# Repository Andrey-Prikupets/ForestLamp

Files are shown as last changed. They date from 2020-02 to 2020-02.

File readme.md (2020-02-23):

# Forest Lamp

Electronic and firmware for that lamp is based on [AlexGyver LED Lamp](https://github.com/AlexGyver/GyverLamp).
The lamp itself is 3D printed as 75% more resized version of that ["resized" model](https://www.thingiverse.com/thing:2657068), which is the remix from original [Forest Lamp](https://www.thingiverse.com/thing:1491062). 
ESP8266 board (I used WeMos D1 mini) runs modified AlexGyver's firmware, where I made some configuration changes, tweaks for stability and flickering removal.
Also I added additional features which are controlled via RemoteXY Android app.

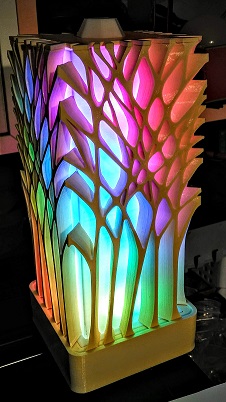
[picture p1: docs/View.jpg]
View


## 3D model changes

I made few additional models and did not use light core. 

* LED core for 8 WS2812 LED stripes with 5 LEDs each (it is low density stripe, stripe with higher number of LEDs is preferable);
* Top cap for the LED core to make it attachable with bolt and nut to the lamp walls and roof;
* Bottom cap to cover gaps between lamp walls and base;
* Crystal-like nut to attach lamp case to the top cap and LED core.

The idea is to disassemble the lamp with only 1 nut.

Models are uploaded to **Thingiverse** [https://www.thingiverse.com/thing:4147654](https://www.thingiverse.com/thing:4147654) :gem:.

## Additional features exposed via RemoteXY app

* Simplified color selection, brightness control and grayscale;
* Alternative on/off switch;
* Special control for focusing lamp beam (a la "radar");
* Russian language interface;

## Parts

* WeMos D1 min;
* 40 WS2812 LEDs on the stripe, cut to 8 pieces by 5 LEDs each.
* 10k resistor pull-up from RST pin to 3.3V;
* 0.1uF ceramic capacitor between 3.3V pin to GND pin (in fact, to the closest pin of RESET button, which is connected to GND);

The last 2 items should decrease chance of freezing ESP8266 on power-up.

## Libraries

* [Modifed version](libraries/RemoteXYap) of [RemoteXY](http://remotexy.com) library where I removed code that creates connection and configures WiFi module (because AlegGyver firmware already does it in a better way).
The library should be placed into library folder as usual.
* All libraries required by AlexGyver's lamp (FastLED etc.).

Note: I also considered using Virtuino, but amazing RGB control and joystick control in RemoteXY forced me to choose RemoteXY.

## RemoteXY UI

RemoteXY UI should be available by [link](http://remotexy.com/en/editor/b432a2957787b45cd5d483b4a82bf226/). 
It works even in free version of RemoteXY Android app, because contains less than 5 controls.
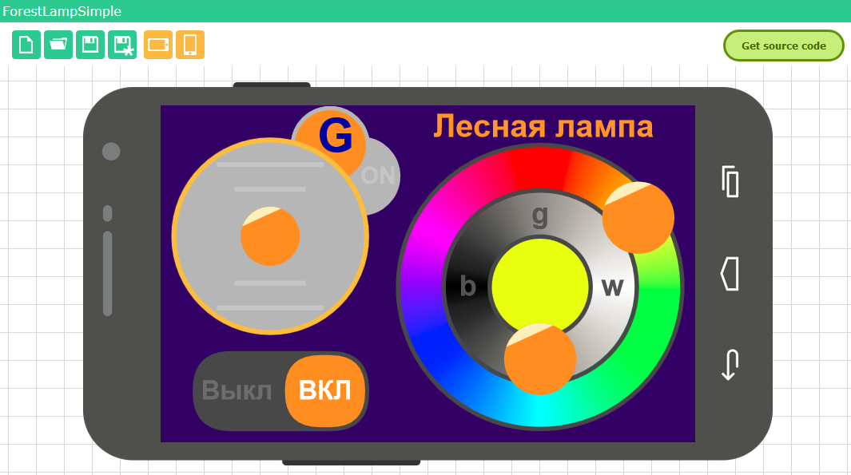
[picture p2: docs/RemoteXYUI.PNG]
UI in designer


## Models
Please see them in [models folder](models). 

## Building photos
Please see them in [docs folder](docs). 

## Internet enabled firmware

Primary firmware is in [firmware/ForestLamp](firmware/ForestLamp) folder.

## Alternative firmware without Internet control

If internet control is not needed, there is an alternative firmware based on Arduino 328p. Effects are changed by pot (variable resistor).
Please see it in [firmware/ForestLampNI](firmware/ForestLampNI) folder.
Video: [https://youtu.be/wpEpOciEXpc](https://youtu.be/wpEpOciEXpc).

## TODO
* Add videos
* Re-enable WDT;

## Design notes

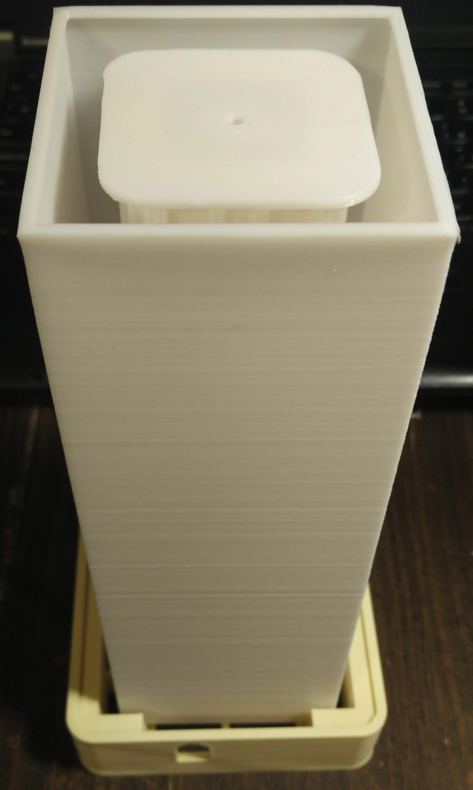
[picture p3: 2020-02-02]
docs/light_core_with_cap2.jpg

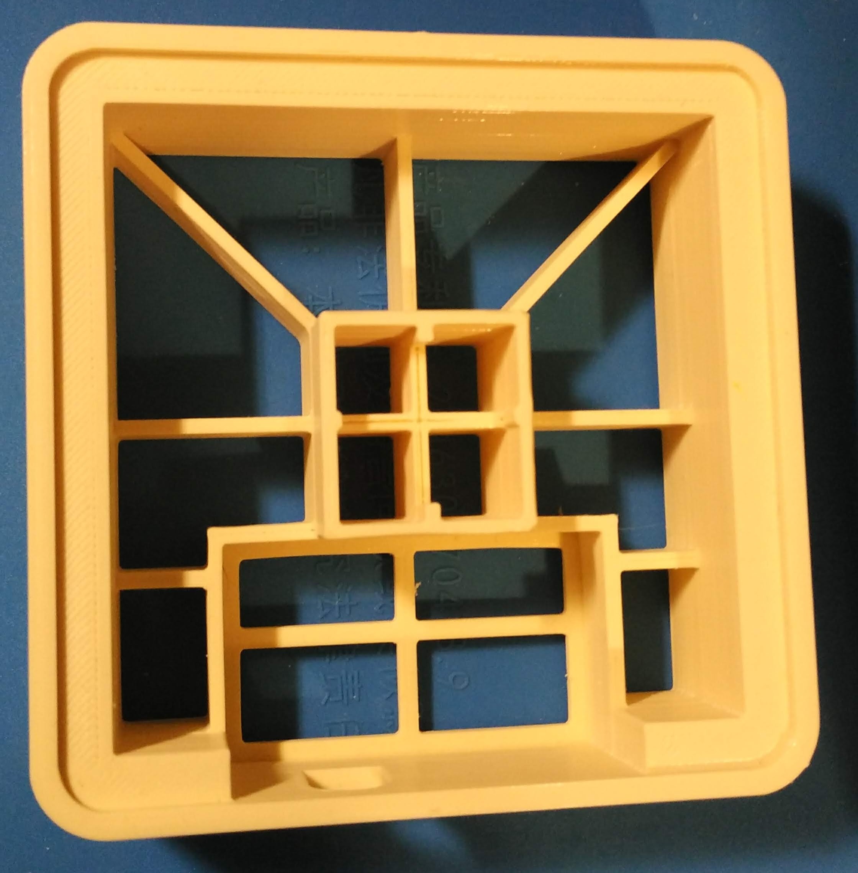
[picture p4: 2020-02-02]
docs/base.jpg

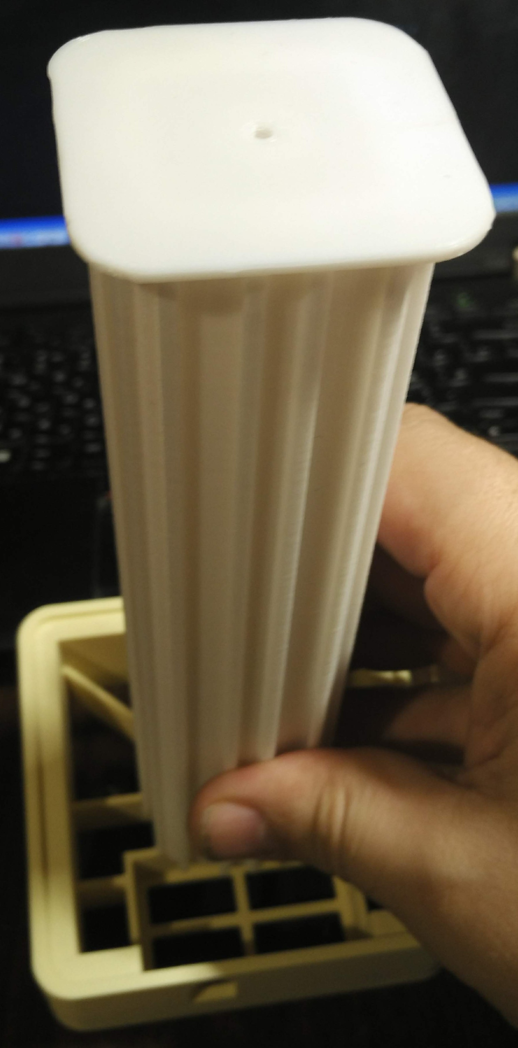
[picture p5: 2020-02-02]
docs/light_core_with_cap_and_base.jpg

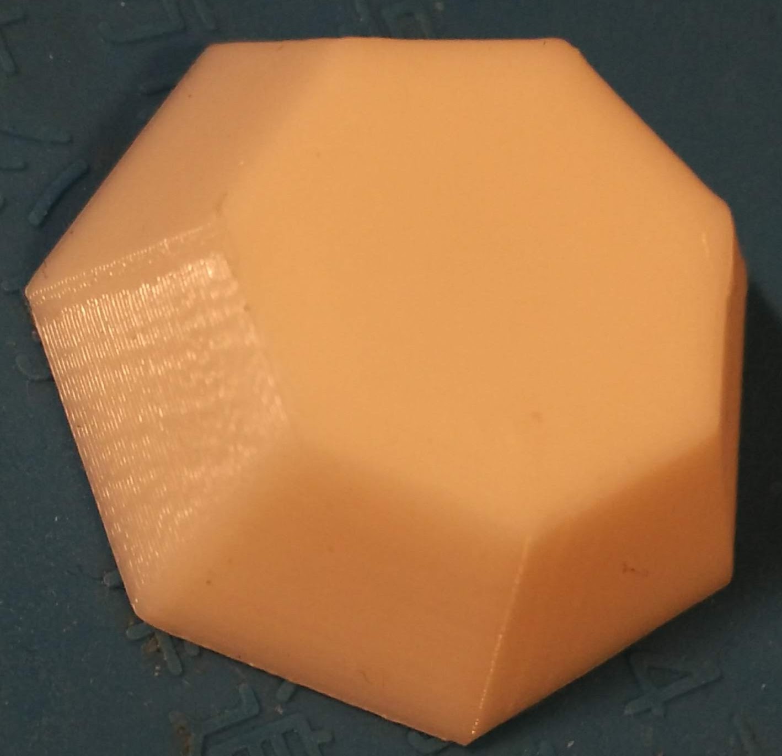
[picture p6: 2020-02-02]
docs/Nut_with_insert_top_view.jpg

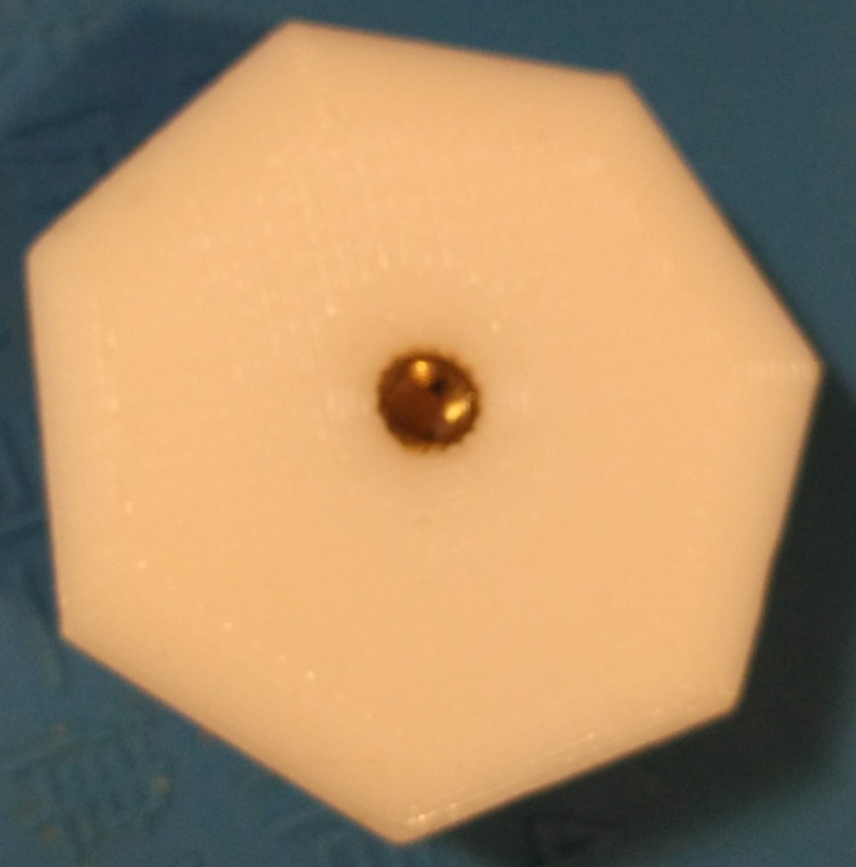
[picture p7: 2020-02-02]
docs/Nut_with_insert_bottom_view.jpg

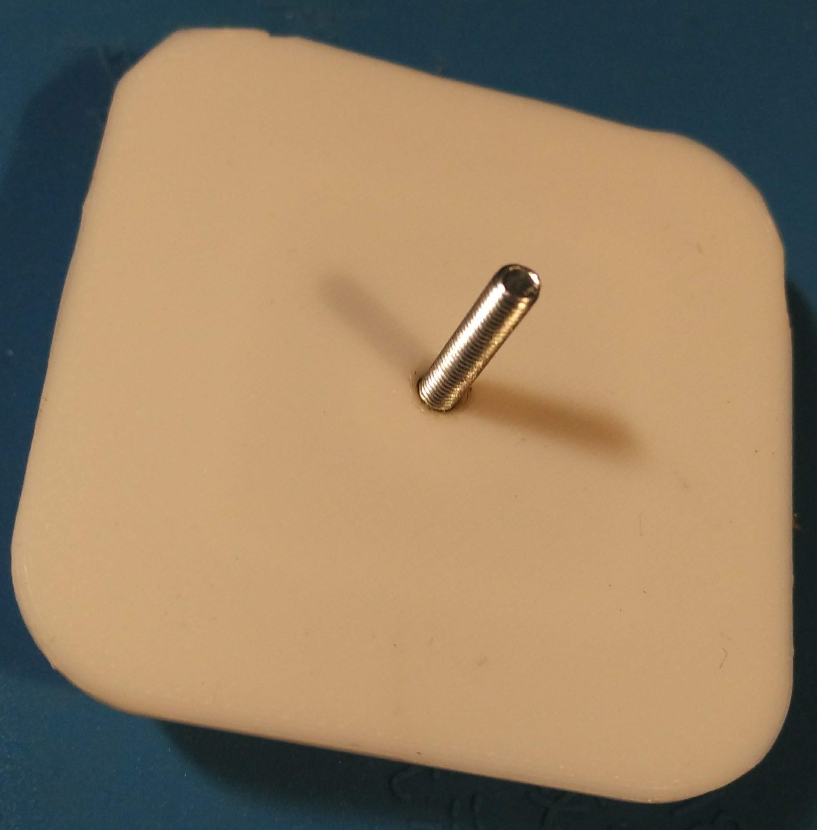
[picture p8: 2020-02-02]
docs/top_cap_top_view.jpg

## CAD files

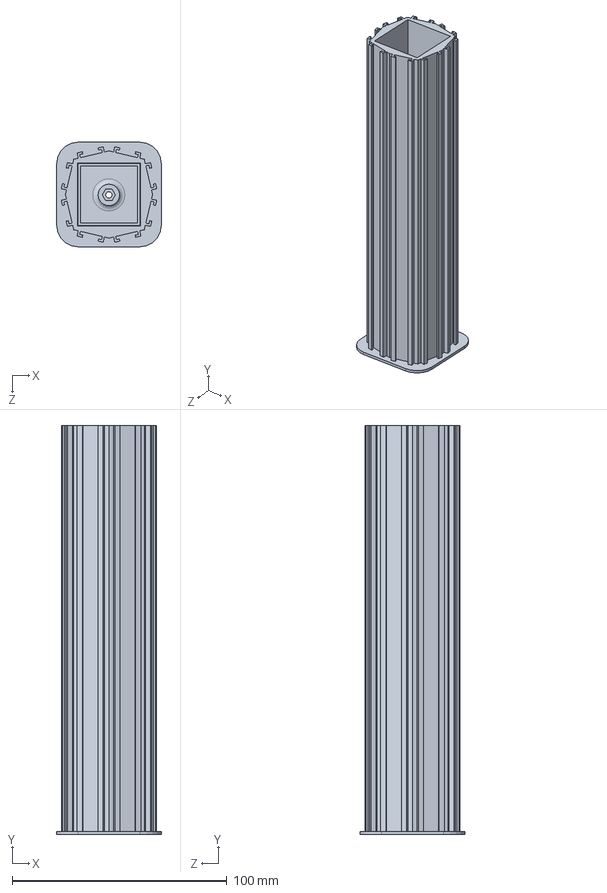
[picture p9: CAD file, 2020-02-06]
models/Light_Pole_and_Top.SLDPRT
48.7 x 190.5 x 48.8 mm

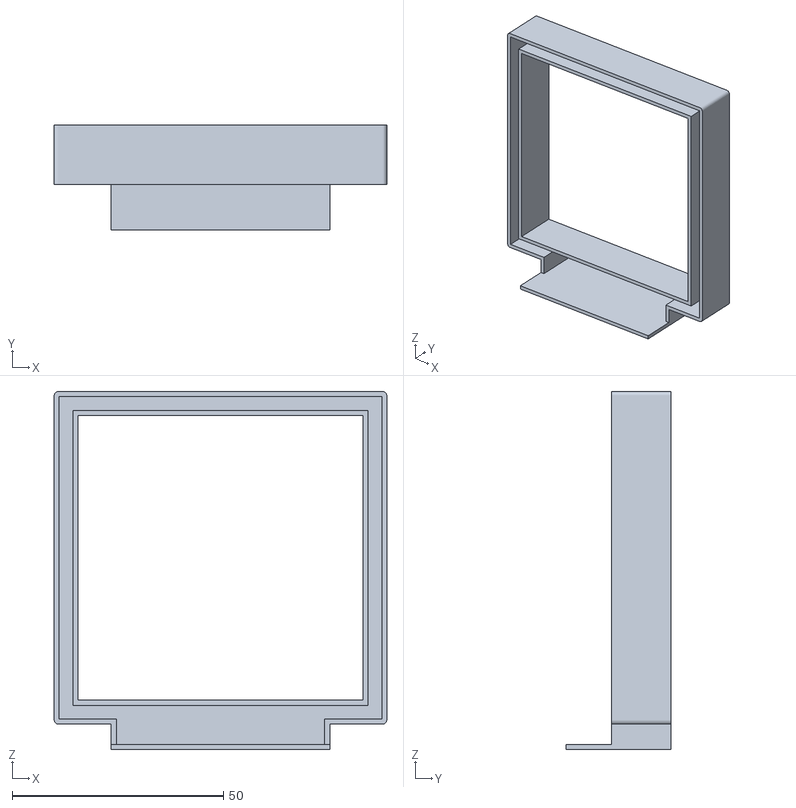
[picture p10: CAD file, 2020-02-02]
models/Lamp_bottom_insert1.STL
78.8 x 24.8 x 84.8

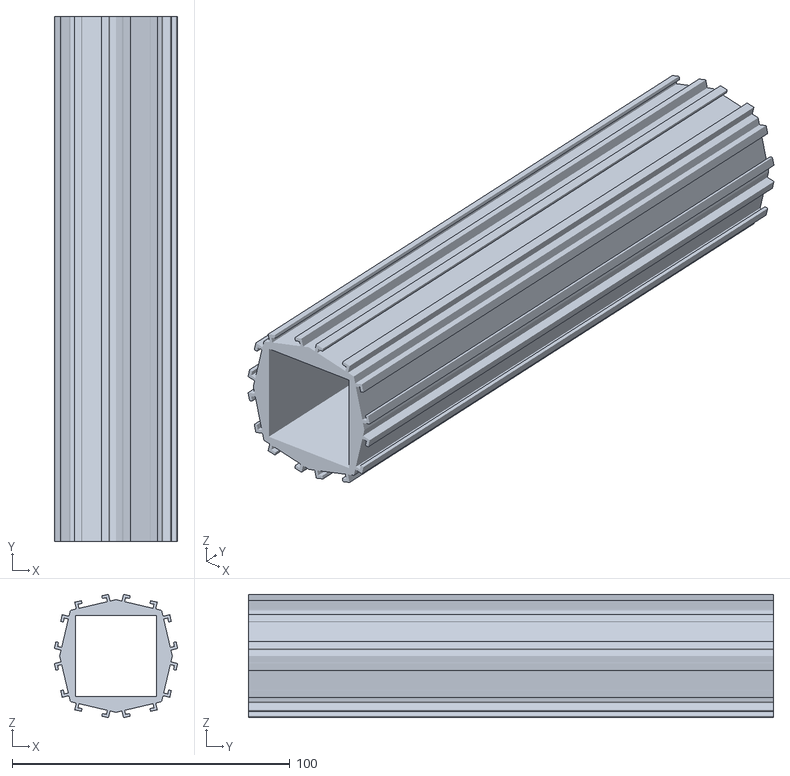
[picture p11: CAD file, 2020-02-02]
models/Light_Pole.STL
44.4 x 189.0 x 44.4

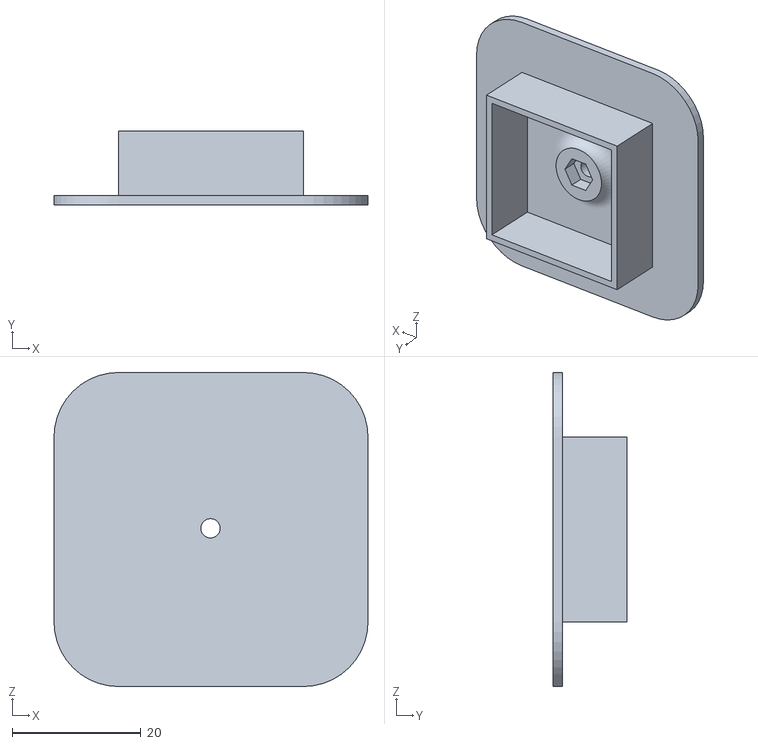
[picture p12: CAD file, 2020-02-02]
models/Light_Pole_Top.STL
48.8 x 11.5 x 48.8

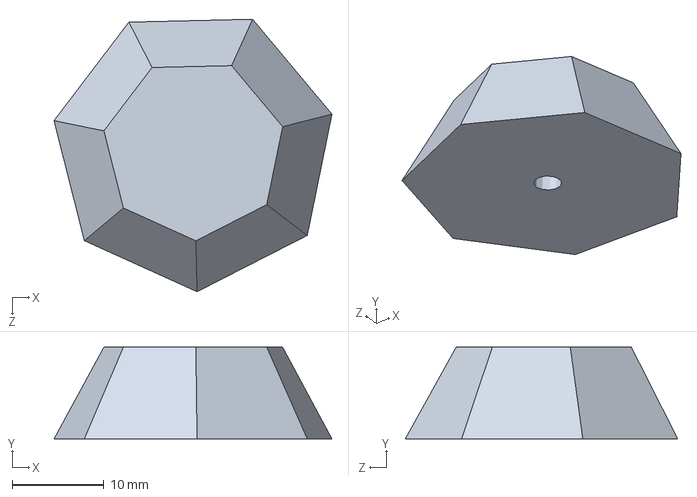
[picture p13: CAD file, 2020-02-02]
models/Lamp Nut.SLDPRT
30.3 x 10.0 x 29.7 mm

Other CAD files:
models/Lamp_bottom_insert.SLDPRT
models/Lamp Nut.STL

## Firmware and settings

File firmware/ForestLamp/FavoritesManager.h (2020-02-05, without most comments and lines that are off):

#pragma once
#include <EEPROM.h>
#include "EepromManager.h"
#include "Constants.h"
#define DEFAULT_FAVORITES_INTERVAL           (300U)         // значение по умолчанию для интервала переключения избранных эффектов в секундах
#define DEFAULT_FAVORITES_DISPERSION         (0U)           // значение по умолчанию для разброса интервала переключения избранных эффектов в секундах
class FavoritesManager
{
  public:
    static uint8_t FavoritesRunning;                        // флаг "работает режим автоматической смены избранных эффектов"
    static uint16_t Interval;                               // статический интервал (время между сменами эффектов)
    static uint16_t Dispersion;                             // дополнительный динамический (случайный) интервал (время между сменами эффектов)
    static uint8_t UseSavedFavoritesRunning;                // флаг, определяющий, нужно ли использовать сохранённое значение FavoritesRunning при перезапуске; еслин нет, "избранное" будет выключено при старте
    static uint8_t FavoriteModes[MODE_AMOUNT];              // массив, каждый элемент которого соответствует флагу "эффект №... добавлен в избранные"
    static void SetStatus(char* statusText)                 // помещает в statusText состояние режима работы избранных эффектов
    {
      char buff[6];
      strcpy_P(statusText, PSTR("FAV "));
      itoa(FavoritesRunning, buff, 10);
      strcat(statusText, buff);
      strcat_P(statusText, PSTR(" "));
      buff[0] = '\0';
      itoa(Interval, buff, 10);
      strcat(statusText, buff);
      strcat_P(statusText, PSTR(" "));
      buff[0] = '\0';
      itoa(Dispersion, buff, 10);
      strcat(statusText, buff);
      strcat_P(statusText, PSTR(" "));
      buff[0] = '\0';
      itoa(UseSavedFavoritesRunning, buff, 10);
      strcat(statusText, buff);
      strcat_P(statusText, PSTR(" "));
      buff[0] = '\0';
      for (uint8_t i = 0; i < MODE_AMOUNT; i++)
      {
        itoa(FavoriteModes[i], buff, 10);
        strcat(statusText, buff);
        if (i < MODE_AMOUNT - 1) strcat_P(statusText, PSTR(" "));
        buff[0] = '\0';
      }
      statusText += '\0';
    }
    static void ConfigureFavorites(const char* statusText)  // принимает statusText, парсит его и инициализирует свойства класса значениями из statusText'а
    {
      FavoritesRunning = getFavoritesRunning(statusText);
      if (FavoritesRunning == 0)
      {
        nextModeAt = 0;
      }
      Interval = getInterval(statusText);
      Dispersion = getDispersion(statusText);
      UseSavedFavoritesRunning = getUseSavedFavoritesRunning(statusText);
      for (uint8_t i = 0; i < MODE_AMOUNT; i++)
      {
        FavoriteModes[i] = getModeOnOff(statusText, i);
      }
    }
    static bool HandleFavorites(                            // функция, обрабатывающая циклическое переключение избранных эффектов; возвращает true, если эффект был переключен
      bool* ONflag,
      int8_t* currentMode,
      bool* loadingFlag
      #ifdef USE_NTP
      , bool* dawnFlag
      #endif
    )
    {
      if (FavoritesRunning == 0 ||
          !*ONflag                                          // лампа не переключается на следующий эффект при выключенной матрице
          #ifdef USE_NTP
          || *dawnFlag                                      // лампа не переключается на следующий эффект при включенном будильнике
          #endif
      )
      {
        return false;
      }
      if (nextModeAt == 0)                                  // лампа не переключается на следующий эффект сразу после включения режима избранных эффектов
      {
        nextModeAt = getNextTime();
        return false;
      }
      if (millis() >= nextModeAt)
      {
        *currentMode = getNextFavoriteMode(currentMode);
        *loadingFlag = true;
        nextModeAt = getNextTime();
        #ifdef GENERAL_DEBUG
        LOG.printf_P(PSTR("Переключение на следующий избранный режим: %d\n\n"), (*currentMode));
        #endif
        return true;
      }
      return false;
    }
    static void ReadFavoritesFromEeprom()
    {
      Interval = EepromManager::ReadUint16(EEPROM_FAVORITES_START_ADDRESS + 1);
      Dispersion = EepromManager::ReadUint16(EEPROM_FAVORITES_START_ADDRESS + 3);
      UseSavedFavoritesRunning = EEPROM.read(EEPROM_FAVORITES_START_ADDRESS + 5);
      FavoritesRunning = UseSavedFavoritesRunning > 0 ? EEPROM.read(EEPROM_FAVORITES_START_ADDRESS) : FavoritesRunning;
      for (uint8_t i = 0; i < MODE_AMOUNT; i++)
      {
        FavoriteModes[i] = EEPROM.read(EEPROM_FAVORITES_START_ADDRESS + i + 6);
        FavoriteModes[i] = FavoriteModes[i] > 0 ? 1 : 0;
      }
    }
    static void SaveFavoritesToEeprom()
    {
      LOG.printf_P(PSTR("SaveFavoritesToEeprom, start=%d\n"), EEPROM_FAVORITES_START_ADDRESS);
      EEPROM.put(EEPROM_FAVORITES_START_ADDRESS, FavoritesRunning);
      EepromManager::WriteUint16(EEPROM_FAVORITES_START_ADDRESS + 1, Interval);
      EepromManager::WriteUint16(EEPROM_FAVORITES_START_ADDRESS + 3, Dispersion);
      EEPROM.put(EEPROM_FAVORITES_START_ADDRESS + 5, UseSavedFavoritesRunning);
      for (uint8_t i = 0; i < MODE_AMOUNT; i++)
      {
        int address = EEPROM_FAVORITES_START_ADDRESS + i + 6;
        EEPROM.put(address, (uint8_t)(FavoriteModes[i] > 0 ? 1 : 0));
      }
      EEPROM.commit();
    }
    static void TurnFavoritesOff()
    {
      FavoritesRunning = 0;
      nextModeAt = 0;
    }
  private:
    static uint32_t nextModeAt;                             // ближайшее время переключения на следующий избранный эффект (millis())
    static bool isStatusTextCorrect(const char* statusText) // валидирует statusText (проверяет, правильное ли количество компонентов он содержит)
    {
      char buff[MAX_UDP_BUFFER_SIZE];
      strcpy(buff, statusText);
      uint8_t lexCount = 0;
      char* p = strtok(buff, " ");
      while (p != NULL)                                   // пока есть лексемы...
      {
        lexCount++;
        p = strtok(NULL, " ");
      }
      return lexCount == getStatusTextNormalComponentsCount();
    }
    static uint8_t getStatusTextNormalComponentsCount()     // возвращает правильное ли коичество компонентов для statusText в зависимости от определённого формата команды и количества эффектов
    {
      return
        1 +          // "FAV"
        1 +          // вкл/выкл
        1 +          // интервал
        1 +          // разброс
        1 +          // использовать ли хранимый вкл/выкл
        MODE_AMOUNT; // 0/1 для каждого эффекта
    }
    static uint8_t getFavoritesRunning(const char* statusText)        // возвращает признак вкл/выкл режима избранных эффектов из statusText
    {
      char lexem[2];
      memset(lexem, 0, 2);
      strcpy(lexem, getLexNo(statusText, 1));
      return lexem != NULL
        ? !strcmp(lexem, "1")
        : 0;
    }
    static uint16_t getInterval(const char* statusText)     // возвращает интервал (постоянную составляющую) переключения избранных эффектов из statusText
    {
      char lexem[6];
      memset(lexem, 0, 6);
      strcpy(lexem, getLexNo(statusText, 2));
      return lexem != NULL
        ? atoi((const char*)lexem)
        : DEFAULT_FAVORITES_INTERVAL;
    }
    static uint16_t getDispersion(const char* statusText)   // возвращает разброс (случайную составляющую) интервала переключения избранных эффектов из statusText
    {
      char lexem[6];
      memset(lexem, 0, 6);
      strcpy(lexem, getLexNo(statusText, 3));
      return lexem != NULL
        ? atoi((const char*)lexem)
        : DEFAULT_FAVORITES_DISPERSION;
    }
    static uint8_t getUseSavedFavoritesRunning(const char* statusText)// возвращает признак вкл/выкл режима избранных эффектов из statusText
    {
      char lexem[2];
      memset(lexem, 0, 2);
      strcpy(lexem, getLexNo(statusText, 4));
      return lexem != NULL
        ? !strcmp(lexem, "1")
        : 0;
    }
    static bool getModeOnOff(const char* statusText, uint8_t modeId)  // возвращает признак включения указанного эффекта в избранные эффекты
    {
      char lexem[2];
      memset(lexem, 0, 2);
      strcpy(lexem, getLexNo(statusText, modeId + 5));
      return lexem != NULL
        ? !strcmp(lexem, "1")
        : false;
    }
    static char* getLexNo(const char* statusText, uint8_t pos)        // служебная функция, разбивает команду statusText на лексемы ("слова", разделённые пробелами) и возвращает указанную по счёту лексему
    {
      if (!isStatusTextCorrect(statusText))
      {
        return NULL;
      }
      const uint8_t buffSize = MAX_UDP_BUFFER_SIZE;
      char buff[buffSize];
      memset(buff, 0, buffSize);
      strcpy(buff, statusText);
      uint8_t lexPos = 0;
      char* p = strtok(buff, " ");
      while (p != NULL)                                   // пока есть лексемы...
      {
        if (lexPos == pos)
        {
          return p;
        }
        p = strtok(NULL, " ");
        lexPos++;
      }
      return NULL;
    }
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

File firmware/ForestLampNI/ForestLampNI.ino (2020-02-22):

#include <FastLED.h>

FASTLED_USING_NAMESPACE


#if defined(FASTLED_VERSION) && (FASTLED_VERSION < 3001000)
#warning "Requires FastLED 3.1 or later; check github for latest code."
#endif

#define POT_PIN     A1
#define OFF_PIN     3

#define DATA_PIN    2
#define LED_TYPE    WS2812

#define WIDTH                 (8U)  // ширина матрицы
#define HEIGHT                (11U) // высота матрицы

#define COLOR_ORDER           (GRB) // порядок цветов на ленте. Если цвет отображается некорректно - меняйте. Начать можно с RGB

#define MATRIX_TYPE           (0U)  // тип матрицы: 0 - зигзаг, 1 - параллельная
#define CONNECTION_ANGLE      (0U)  // угол подключения: 0 - левый нижний, 1 - левый верхний, 2 - правый верхний, 3 - правый нижний
#define STRIP_DIRECTION       (1U)  // направление ленты из угла: 0 - вправо, 1 - вверх, 2 - влево, 3 - вниз
                                    // при неправильной настройке матрицы вы получите предупреждение "Wrong matrix parameters! Set to default"
                                    // шпаргалка по настройке матрицы здесь! https://alexgyver.ru/matrix_guide/
#define NUM_LEDS              (uint16_t)(WIDTH * HEIGHT)
CRGB leds[NUM_LEDS];

#define BRIGHTNESS         255 // 0-255
#define FRAMES_PER_SECOND  120

#define NUM_READINGS          (10)

#define SEGMENTS              (1U)                          // диодов в одном "пикселе" (для создания матрицы из кусков ленты)

uint8_t gCurrentPatternNumber = 0; // Index number of which pattern is current
uint8_t gHue = 0; // rotating "base color" used by many of the patterns

bool loadingFlag = true;
unsigned char matrixValue[8][16];

// Scale in range 1..100;
// Delay in ms;
#define FIRE_SCALE        10 // yellow fire;
#define FIRE_DELAY        10

#define RAINBOW_VER_SCALE 25 // 10
#define RAINBOW_VER_DELAY 100

#define RAINBOW_HOR_SCALE 10
#define RAINBOW_HOR_DELAY 100

#define RAINBOW_DIAG_SCALE 15
#define RAINBOW_DIAG_DELAY 80

#define MATRIX_SCALE      50
#define MATRIX_DELAY      100

static const uint8_t maxDim = max(WIDTH, HEIGHT);

// START; Effects from FastLed's DemoReel;

void rainbow() 
{
  // FastLED's built-in rainbow generator
  fill_rainbow( leds, NUM_LEDS, gHue, 7);
}

void rainbowWithGlitter() 
{
  // built-in FastLED rainbow, plus some random sparkly glitter
  rainbow();
  addGlitter(80);
}

void addGlitter( fract8 chanceOfGlitter) 
{
  if( random8() < chanceOfGlitter) {
    leds[ random16(NUM_LEDS) ] += CRGB::White;
  }
}

void confetti() 
{
  // random colored speckles that blink in and fade smoothly
  fadeToBlackBy( leds, NUM_LEDS, 10);
  int pos = random16(NUM_LEDS);
  leds[pos] += CHSV( gHue + random8(64), 200, 255);
}

void sinelon()
{
  // a colored dot sweeping back and forth, with fading trails
  fadeToBlackBy( leds, NUM_LEDS, 20);
  int pos = beatsin16( 13, 0, NUM_LEDS-1 );
  leds[pos] += CHSV( gHue, 255, 192);
}

void bpm()
{
  // colored stripes pulsing at a defined Beats-Per-Minute (BPM)
  uint8_t BeatsPerMinute = 62;
  CRGBPalette16 palette = PartyColors_p;
  uint8_t beat = beatsin8( BeatsPerMinute, 64, 255);
  for( int i = 0; i < NUM_LEDS; i++) { //9948
    leds[i] = ColorFromPalette(palette, gHue+(i*2), beat-gHue+(i*10));
  }
}

void juggle() {
  // eight colored dots, weaving in and out of sync with each other
  fadeToBlackBy( leds, NUM_LEDS, 20);
  byte dothue = 0;
  for( int i = 0; i < 8; i++) {
    leds[beatsin16( i+7, 0, NUM_LEDS-1 )] |= CHSV(dothue, 200, 255);
    dothue += 32;
  }
}

// END; Effects from FastLed's DemoReel;

// START; Effects from AlexGyver's WiFi Lamp;

// служебные функции

// залить все
void fillAll(CRGB color)
{
  for (int32_t i = 0; i < NUM_LEDS; i++)
  {
    leds[i] = color;
  }
}

// функция отрисовки точки по координатам X Y
void drawPixelXY(int16_t x, int16_t y, CRGB color)
{
  if (x < 0 || x > (int16_t)(WIDTH - 1) || y < 0 || y > (int16_t)(HEIGHT - 1)) return;
  uint32_t thisPixel = getPixelNumber((uint8_t)x, (uint8_t)y) * SEGMENTS;
  for (uint8_t i = 0; i < SEGMENTS; i++)
  {
    leds[thisPixel + i] = color;
  }
}

// функция получения цвета пикселя по его номеру
uint32_t getPixColor(uint32_t thisSegm)
{
  uint32_t thisPixel = thisSegm * SEGMENTS;
  if (thisPixel > NUM_LEDS - 1) return 0;
  return (((uint32_t)leds[thisPixel].r << 16) | ((uint32_t)leds[thisPixel].g << 8 ) | (uint32_t)leds[thisPixel].b);
}

// функция получения цвета пикселя в матрице по его координатам
uint32_t getPixColorXY(uint8_t x, uint8_t y)
{
  return getPixColor(getPixelNumber(x, y));
}

// ************* НАСТРОЙКА МАТРИЦЫ *****
#if (CONNECTION_ANGLE == 0 && STRIP_DIRECTION == 0)
#define _WIDTH WIDTH
#define THIS_X x
#define THIS_Y y

#elif (CONNECTION_ANGLE == 0 && STRIP_DIRECTION == 1)
#define _WIDTH HEIGHT
#define THIS_X y
#define THIS_Y x

#elif (CONNECTION_ANGLE == 1 && STRIP_DIRECTION == 0)
#define _WIDTH WIDTH
#define THIS_X x
#define THIS_Y (HEIGHT - y - 1)

#elif (CONNECTION_ANGLE == 1 && STRIP_DIRECTION == 3)
#define _WIDTH HEIGHT
#define THIS_X (HEIGHT - y - 1)
#define THIS_Y x

#elif (CONNECTION_ANGLE == 2 && STRIP_DIRECTION == 2)
#define _WIDTH WIDTH
#define THIS_X (WIDTH - x - 1)
#define THIS_Y (HEIGHT - y - 1)

#elif (CONNECTION_ANGLE == 2 && STRIP_DIRECTION == 3)
#define _WIDTH HEIGHT
#define THIS_X (HEIGHT - y - 1)
#define THIS_Y (WIDTH - x - 1)

#elif (CONNECTION_ANGLE == 3 && STRIP_DIRECTION == 2)
#define _WIDTH WIDTH
#define THIS_X (WIDTH - x - 1)
#define THIS_Y y

#elif (CONNECTION_ANGLE == 3 && STRIP_DIRECTION == 1)
#define _WIDTH HEIGHT
#define THIS_X y
#define THIS_Y (WIDTH - x - 1)

#else
#define _WIDTH WIDTH
#define THIS_X x
#define THIS_Y y
#pragma message "Wrong matrix parameters! Set to default"

#endif

// получить номер пикселя в ленте по координатам
uint16_t getPixelNumber(uint8_t x, uint8_t y)
{
  if ((THIS_Y % 2 == 0) || MATRIX_TYPE)                     // если чётная строка
  {
    return (THIS_Y * _WIDTH + THIS_X);
  }
  else                                                      // если нечётная строка
  {
    return (THIS_Y * _WIDTH + _WIDTH - THIS_X - 1);
  }
}

uint8_t line[WIDTH];
uint8_t pcnt = 0U;
#define SPARKLES              (1U)                          // вылетающие угольки вкл выкл

//these values are substracetd from the generated values to give a shape to the animation
static const uint8_t valueMask[8][16] PROGMEM =
{
  {32 , 0  , 0  , 0  , 0  , 0  , 0  , 32 , 32 , 0  , 0  , 0  , 0  , 0  , 0  , 32 },
  {64 , 0  , 0  , 0  , 0  , 0  , 0  , 64 , 64 , 0  , 0  , 0  , 0  , 0  , 0  , 64 },
  {96 , 32 , 0  , 0  , 0  , 0  , 32 , 96 , 96 , 32 , 0  , 0  , 0  , 0  , 32 , 96 },
  {128, 64 , 32 , 0  , 0  , 32 , 64 , 128, 128, 64 , 32 , 0  , 0  , 32 , 64 , 128},
  {160, 96 , 64 , 32 , 32 , 64 , 96 , 160, 160, 96 , 64 , 32 , 32 , 64 , 96 , 160},
  {192, 128, 96 , 64 , 64 , 96 , 128, 192, 192, 128, 96 , 64 , 64 , 96 , 128, 192},
  {255, 160, 128, 96 , 96 , 128, 160, 255, 255, 160, 128, 96 , 96 , 128, 160, 255},
  {255, 192, 160, 128, 128, 160, 192, 255, 255, 192, 160, 128, 128, 160, 192, 255}
};

//these are the hues for the fire,
//should be between 0 (red) to about 25 (yellow)
static const uint8_t hueMask[8][16] PROGMEM =
{
  {1 , 11, 19, 25, 25, 22, 11, 1 , 1 , 11, 19, 25, 25, 22, 11, 1 },
  {1 , 8 , 13, 19, 25, 19, 8 , 1 , 1 , 8 , 13, 19, 25, 19, 8 , 1 },
  {1 , 8 , 13, 16, 19, 16, 8 , 1 , 1 , 8 , 13, 16, 19, 16, 8 , 1 },
  {1 , 5 , 11, 13, 13, 13, 5 , 1 , 1 , 5 , 11, 13, 13, 13, 5 , 1 },
  {1 , 5 , 11, 11, 11, 11, 5 , 1 , 1 , 5 , 11, 11, 11, 11, 5 , 1 },
  {0 , 1 , 5 , 8 , 8 , 5 , 1 , 0 , 0 , 1 , 5 , 8 , 8 , 5 , 1 , 0 },
  {0 , 0 , 1 , 5 , 5 , 1 , 0 , 0 , 0 , 0 , 1 , 5 , 5 , 1 , 0 , 0 },
  {0 , 0 , 0 , 1 , 1 , 0 , 0 , 0 , 0 , 0 , 0 , 1 , 1 , 0 , 0 , 0 }
};

void fireRoutine()
{
  if (loadingFlag)
  {
    loadingFlag = false;
    FastLED.clear();
    generateLine();
    memset(matrixValue, 0, sizeof(matrixValue));
  }
  EVERY_N_MILLISECONDS( FIRE_DELAY ) {
    if (pcnt >= 100)
    {
      shiftUp();
      generateLine();
      pcnt = 0;
    }
    drawFrame(pcnt, true);
    pcnt += 30;
  }
}

// Randomly generate the next line (matrix row)
void generateLine()
{
  for (uint8_t x = 0U; x < WIDTH; x++)
  {
    line[x] = random(64, 255);
  }
}

void shiftUp()
{
  for (uint8_t y = HEIGHT - 1U; y > 0U; y--)
  {
    for (uint8_t x = 0U; x < WIDTH; x++)
    {
      uint8_t newX = x;
      if (x > 15U) newX = x % 16U;
      if (y > 7U) continue;
      matrixValue[y][newX] = matrixValue[y - 1U][newX];
    }
  }

  for (uint8_t x = 0U; x < WIDTH; x++)
  {
    uint8_t newX = x;
    if (x > 15U) newX = x % 16U;
    matrixValue[0U][newX] = line[newX];
  }
}

// draw a frame, interpolating between 2 "key frames"
// @param pcnt percentage of interpolation

void drawFrame(uint8_t pcnt, bool isColored)
{
  int32_t nextv;

  //each row interpolates with the one before it
  for (uint8_t y = HEIGHT - 1U; y > 0U; y--)
  {
    for (uint8_t x = 0U; x < WIDTH; x++)
    {
      uint8_t newX = x;
      if (x > 15U) newX = x % 16U;
      if (y < 8U)
      {
        nextv =
          (((100.0 - pcnt) * matrixValue[y][newX]
            + pcnt * matrixValue[y - 1][newX]) / 100.0)
          - pgm_read_byte(&valueMask[y][newX]);

        CRGB color = CHSV(
          isColored ? FIRE_SCALE * 2.5 + pgm_read_byte(&hueMask[y][newX]) : 0U,     // H
          isColored ? 255U : 0U,                                                               // S
          (uint8_t)max(0, nextv)                                                               // V
        );

        leds[getPixelNumber(x, y)] = color;
      }
      else if (y == 8U && SPARKLES)
      {
        if (random(0, 20) == 0 && getPixColorXY(x, y - 1U) != 0U) drawPixelXY(x, y, getPixColorXY(x, y - 1U));
        else drawPixelXY(x, y, 0U);
      }
      else if (SPARKLES)
      {
        // старая версия для яркости
        if (getPixColorXY(x, y - 1U) > 0U)
          drawPixelXY(x, y, getPixColorXY(x, y - 1U));
        else drawPixelXY(x, y, 0U);
      }
    }
  }

  //first row interpolates with the "next" line
  for (uint8_t x = 0U; x < WIDTH; x++)
  {
    uint8_t newX = x;
    if (x > 15U) newX = x % 16U;
    CRGB color = CHSV(
      isColored ? FIRE_SCALE * 2.5 + pgm_read_byte(&(hueMask[0][newX])): 0U,        // H
      isColored ? 255U : 0U,                                                                   // S
      (uint8_t)(((100.0 - pcnt) * matrixValue[0][newX] + pcnt * line[newX]) / 100.0)           // V
    );
    //leds[getPixelNumber(newX, 0)] = color;                                         // на форуме пишут что это ошибка - вместо newX должно быть x, иначе
    leds[getPixelNumber(x, 0)] = color;                                              // на матрицах шире 16 столбцов нижний правый угол неработает
  }
}

// ------------- радуга вертикальная ----------------
// uint8_t hue;

#define hue gHue

void rainbowVerticalRoutine()
{
  EVERY_N_MILLISECONDS( RAINBOW_VER_DELAY ) {
    hue += 4;
    for (uint8_t j = 0; j < HEIGHT; j++)
    {
      CHSV thisColor = CHSV((uint8_t)(hue + j * RAINBOW_VER_SCALE), 255, 255);
      for (uint8_t i = 0U; i < WIDTH; i++)
      {
        drawPixelXY(i, j, thisColor);
      }
    }
  }
}

// ------------- радуга горизонтальная ----------------
void rainbowHorizontalRoutine()
{
  EVERY_N_MILLISECONDS( RAINBOW_HOR_DELAY ) {
    hue += 4;
    for (uint8_t i = 0U; i < WIDTH; i++)
    {
      CHSV thisColor = CHSV((uint8_t)(hue + i * RAINBOW_HOR_SCALE), 255, 255);
      for (uint8_t j = 0U; j < HEIGHT; j++)
      {
        drawPixelXY(i, j, thisColor);
      }
    }
  }
}

// ------------- радуга диагональная -------------
void rainbowDiagonalRoutine()
{
  if (loadingFlag)
  {
    loadingFlag = false;
    FastLED.clear();
  }

  EVERY_N_MILLISECONDS( RAINBOW_DIAG_DELAY ) {
    hue += 8;
    for (uint8_t i = 0U; i < WIDTH; i++)
    {
      for (uint8_t j = 0U; j < HEIGHT; j++)
      {
        float twirlFactor = 3.0F * (RAINBOW_DIAG_SCALE / 100.0F);      // на сколько оборотов будет закручена матрица, [0..3]
        uint8_t hue1 = (uint8_t)(hue + ((float)WIDTH / (float)HEIGHT * i + j * twirlFactor) * (float)(255 / maxDim));
        CRGB thisColor = CHSV(hue1, 255, 255);
        drawPixelXY(i, j, thisColor);
      }
    }
  }
}

// ------------- матрица ---------------
void matrixRoutine()
{
  if (loadingFlag)
  {
    loadingFlag = false;
    FastLED.clear();
  }
  EVERY_N_MILLISECONDS( MATRIX_DELAY ) {
    for (uint8_t x = 0U; x < WIDTH; x++)
    {
      // заполняем случайно верхнюю строку
      uint32_t thisColor = getPixColorXY(x, HEIGHT - 1U);
      if (thisColor == 0U)
        drawPixelXY(x, HEIGHT - 1U, 0x00FF00 * (random(0, 100 - MATRIX_SCALE) == 0U));
      else if (thisColor < 0x002000)
        drawPixelXY(x, HEIGHT - 1U, 0U);
      else
        drawPixelXY(x, HEIGHT - 1U, thisColor - 0x002000);
    }
  
    // сдвигаем всё вниз
    for (uint8_t x = 0U; x < WIDTH; x++)
    {
      for (uint8_t y = 0U; y < HEIGHT - 1U; y++)
      {
        drawPixelXY(x, y, getPixColorXY(x, y + 1U));
      }
    }
  }
}

// END; Effects from AlexGyver's WiFi Lamp;

int readings[NUM_READINGS];     // the readings from the analog input

void setup() {
  Serial.begin(115200);
  // tell FastLED about the LED strip configuration
  FastLED.addLeds<LED_TYPE,DATA_PIN,COLOR_ORDER>(leds, NUM_LEDS).setCorrection(TypicalLEDStrip);
  // set master brightness control
  FastLED.setBrightness(BRIGHTNESS);

  pinMode(POT_PIN, INPUT); // set pin to input;
  digitalWrite(POT_PIN, LOW); // disable pull-ups;
     
  pinMode(OFF_PIN, INPUT); // set pin to input;
  digitalWrite(OFF_PIN, HIGH); // enable pull-ups;
  
  for (int i = 0; i < NUM_READINGS; i++) {
    readings[i] = 0;
  }

  memset(matrixValue, 0, sizeof(matrixValue));
  randomSeed(micros());
  loadingFlag = true;
}

static int rawValue = 0;

int getValueAvg() {
  static int readIndex = 0;              // the index of the current reading
  static int total = 0;                  // the running total
  
  // subtract the last reading:
  total = total - readings[readIndex];
  // read from the sensor:
  rawValue = analogRead(POT_PIN);
  readings[readIndex] = rawValue;
  // add the reading to the total:
  total = total + readings[readIndex];
  // advance to the next position in the array:
  readIndex = readIndex + 1;

  // if we're at the end of the array...
  if (readIndex >= NUM_READINGS) {
    // ...wrap around to the beginning:
    readIndex = 0;
  }

  // calculate the average:
  return total / NUM_READINGS;
}

#define ADC_MAX 1023

int getValue() {
  int value = ADC_MAX-getValueAvg();
  static int value1 = -1;
  if (value != value1) {
//    Serial.print("value="); Serial.print(value,DEC);
//    Serial.print(", rawValue="); Serial.println(rawValue,DEC);
    value1 = value;
  } else {
//    Serial.print("rawValue="); Serial.println(rawValue,DEC);  
  }
  return value;  
}

// List of patterns to cycle through.  Each is defined as a separate function below.
typedef void (*SimplePatternList[])();
//   rainbow,            
//   juggle,              
//   rainbowWithGlitter, 
//   bpm,
SimplePatternList gPatterns = { 
   confetti,            
   sinelon,             
   fireRoutine,
   rainbowVerticalRoutine,
   rainbowHorizontalRoutine,
   rainbowDiagonalRoutine,
   matrixRoutine
  };              

#define ARRAY_SIZE(A) (sizeof(A) / sizeof((A)[0]))

#define SAFE_LIMIT 100 // dirty hack to handle out of range values;
#define POT_MIN 0
#define POT_MAX ADC_MAX
#define POT_MIN_SAFE (POT_MIN-SAFE_LIMIT)
#define POT_MAX_SAFE (POT_MAX+SAFE_LIMIT)
#define POT_WHITE_MIN 0
#define POT_WHITE_MIN_SAFE POT_MIN_SAFE
#define POT_WHITE_MAX 40
#define POT_COLORS_MIN POT_WHITE_MAX+1
#define POT_COLORS_MAX (POT_MAX/4)
#define EFFECTS_MIN (POT_COLORS_MAX+1)
#define EFFECTS_MAX (POT_MAX-40)
#define DEMO_MIN (EFFECTS_MAX+1)
#define DEMO_MAX POT_MAX
#define DEMO_MAX_SAFE POT_MAX_SAFE
#define EFFECTS_RANGE (EFFECTS_MAX-EFFECTS_MIN+1)
#define EFFECTS_NUM ARRAY_SIZE(gPatterns)
#define EFFECTS_STEP (EFFECTS_RANGE/EFFECTS_NUM)

#define HIST_STEP ((EFFECTS_STEP+7)/8)

void nextPattern()
{
  // add one to the current pattern number, and wrap around at the end
  gCurrentPatternNumber = (gCurrentPatternNumber + 1) % ARRAY_SIZE( gPatterns);
  Serial.print(F("Pattern ")); Serial.println(gCurrentPatternNumber, DEC);
}

void setAllLeds(CHSV color) {
  CRGB col = (CRGB) color;
  for( int i = 0; i < NUM_LEDS; i++) {
    leds[i] = col;
  }  
}

bool inRange1(int value, int minValue, int maxValue) {
  return value >= minValue && value <= maxValue;
}

bool inRange(int value, int minValue, int maxValue) {
  static int prevValue = -1;
  bool prevValueInRange = inRange1(prevValue, minValue, maxValue);
  bool fit;
//  Serial.print(F("prevValueInRange=")); Serial.print(prevValueInRange, DEC);
  if (prevValueInRange) {
//    Serial.print(F(", step=")); Serial.print(HIST_STEP, DEC);
    fit = inRange1(value, minValue-HIST_STEP, maxValue+HIST_STEP);
  } else {
    fit = inRange1(value, minValue+HIST_STEP, maxValue-HIST_STEP);    
  }
  if (fit) {
    prevValue = (maxValue+minValue)/2;
  }
//  Serial.print(F(" [")); Serial.print(minValue, DEC);
//  Serial.print(F(",")); Serial.print(maxValue, DEC);
//  Serial.print(F("], value=")); Serial.print(value, DEC);
//  Serial.print(F(", fit=")); Serial.println(fit, DEC);
  return fit;
}

bool isSwitched(int pos) {
  static int pos1 = -1;
  if (pos != pos1) {
    Serial.print(F("Triggered to ")); Serial.println(pos, DEC);
    pos1 = pos;
    return true;
  }
  return false;
}

void loop()
{
  // insert a delay to keep the framerate modest
  FastLED.delay(1000/FRAMES_PER_SECOND); 

  if (digitalRead(OFF_PIN)) {
    FastLED.clear();
    FastLED.show();  
    return;
  }

  int value = getValue();
  if (inRange(value, POT_WHITE_MIN_SAFE, POT_WHITE_MAX)) {
    isSwitched(POT_WHITE_MIN);
    setAllLeds(CHSV(0, 0, 255));
  } else
  if (inRange(value, POT_COLORS_MIN, POT_COLORS_MAX)) {
    isSwitched(POT_COLORS_MIN);
    int hue = constrain(map(value,POT_COLORS_MIN,POT_COLORS_MAX,0,255), 0, 255);
    setAllLeds(CHSV(hue, 255, 255));
  } else
  if (inRange(value, EFFECTS_MIN, EFFECTS_MAX)) {
    int effect = map(value,EFFECTS_MIN,EFFECTS_MAX,0,EFFECTS_NUM);
    #define ARTIFICIAL_EFFECTS_HASH_BASE 10000
    if (isSwitched(ARTIFICIAL_EFFECTS_HASH_BASE+effect)) {
      loadingFlag = true;  
      gHue = 0;
    }
    EVERY_N_MILLISECONDS( 20 ) { gHue++; } // slowly cycle the "base color" through the rainbow
    gPatterns[effect]();
  } else
  if (inRange(value, DEMO_MIN, DEMO_MAX_SAFE)) {
    if (isSwitched(DEMO_MIN)) {
      gCurrentPatternNumber = 0;
      gHue = 0;
    }
    // Call the current pattern function once, updating the 'leds' array
    gPatterns[gCurrentPatternNumber]();
    
    // do some periodic updates
    EVERY_N_MILLISECONDS( 20 ) { gHue++; } // slowly cycle the "base color" through the rainbow
    EVERY_N_SECONDS( 10 ) { nextPattern(); } // change patterns periodically    
  } else {
//    Serial.println(value);
  }

  // send the 'leds' array out to the actual LED strip
  FastLED.show();    
}

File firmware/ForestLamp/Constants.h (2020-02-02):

#pragma once

#include <ESP8266WebServer.h>


// ============= НАСТРОЙКИ =============
// --- ESP -----------------------------
#define ESP_MODE              (1U)                          // 0U - WiFi точка доступа, 1U - клиент WiFi (подключение к роутеру)
uint8_t espMode = ESP_MODE;                                 // ESP_MODE может быть сохранён в энергонезависимую память и изменён в процессе работы лампы без необходимости её перепрошивки
///#define ESP_USE_BUTTON                                      // если строка не закомментирована, должна быть подключена кнопка (иначе ESP может регистрировать "фантомные" нажатия и некорректно устанавливать яркость)
#if defined (ESP_USE_BUTTON)
#define BUTTON_STEP_TIMEOUT   (100U)                        // каждые BUTTON_STEP_TIMEOUT мс будет генерироваться событие удержания кнопки (для регулировки яркости)
#define BUTTON_CLICK_TIMEOUT  (500U)                        // максимальное время между нажатиями кнопки в мс, до достижения которого считается серия последовательных нажатий
#endif
#define ESP_RESET_ON_START    (false)                       // true - если при старте нажата кнопка (или кнопки нет!), сохранённые настройки будут сброшены; false - не будут
#define ESP_HTTP_PORT         (80U)                         // номер порта, который будет использоваться во время первой утановки имени WiFi сети (и пароля), к которой потом будет подключаться лампа в режиме WiFi клиента (лучше не менять)
#define ESP_UDP_PORT          (8888U)                       // номер порта, который будет "слушать" UDP сервер во время работы лампы как в режиме WiFi точки доступа, так и в режиме WiFi клиента (лучше не менять)
#define ESP_CONN_TIMEOUT      (7U)                          // время в секундах (ДОЛЖНО БЫТЬ МЕНЬШЕ 8, иначе сработает WDT), которое ESP будет пытаться подключиться к WiFi сети, после его истечения автоматически развернёт WiFi точку доступа
#define ESP_CONF_TIMEOUT      (300U)                        // время в секундах, которое ESP будет ждать ввода SSID и пароля WiFi сети роутера в конфигурационном режиме, после его истечения ESP перезагружается
#define GENERAL_DEBUG                                       // если строка не закомментирована, будут выводиться отладочные сообщения
#define WIFIMAN_DEBUG         (true)                        // вывод отладочных сообщений при подключении к WiFi сети: true - выводятся, false - не выводятся; настройка не зависит от GENERAL_DEBUG
///#define OTA                                                 // если строка не закомментирована, модуль будет ждать два последдовательных запроса пользователя на прошивку по воздуху (см. документацию в "шапке")
#ifdef OTA
#define ESP_OTA_PORT          (8266U)                       // номер порта, который будет "прослушиваться" в ожидании команды прошивки по воздуху
#endif
//#define LED_PIN               (2U)                          // пин ленты                (D4)
/// AP; Don't use D4 in Wemos otherwise built-in blue LED will always shine!
#define LED_PIN               (D2)                          // пин ленты               
#define BUILT_IN_LED_PIN      (D4)
///#define BTN_PIN               (4U)                          // пин кнопки               (D2)
///#define MOSFET_PIN            (5U)                          // пин MOSFET транзистора   (D1) - может быть использован для управления питанием матрицы/ленты
///#define ALARM_PIN             (16U)                         // пин состояния будильника (D0) - может быть использован для управления каким-либо внешним устройством на время работы будильника
///#define MOSFET_LEVEL          (HIGH)                        // логический уровень, в который будет установлен пин MOSFET_PIN, когда матрица включена - HIGH или LOW
#define ALARM_LEVEL           (HIGH)                        // логический уровень, в который будет установлен пин ALARM_PIN, когда "рассвет"/будильник включен
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

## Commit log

2020-02-02 second commit
    [Lamp Nut.SLDPRT, Lamp Nut.STL, Lamp_bottom_insert.SLDPRT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]
2020-02-04 Fixed HSV colors issue - color was sometimes not adequate;
    [ForestLamp.ino]
2020-02-05 Fixed issues with saving current mode;
    [EepromManager.h, FavoritesManager.h, ForestLamp.ino]
2020-02-06 Added Light Pole and Top model.
    [Light_Pole_and_Top.SLDPRT]
2020-02-22 Fixed issue when lamp did not work if pot is in the edge position;
    [ForestLampNI.ino]
